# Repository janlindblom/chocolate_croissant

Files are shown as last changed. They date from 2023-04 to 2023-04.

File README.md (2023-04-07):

# The Chocolate Croissant

Yeah the name is stupid, I know.

This is a breakout board for when you want to fit a Raspberry Pi [34] B hat
onto a Raspberry Pi Pico or fit a Raspberry Pi Pico in something that expects a
full Raspberry Pi [34] B+.

The Raspberry Pi Pico W fits too of course.

## Pinout

The pinout might not be what you expect since the idea is to map function to
function rather than GPIO pin to pin.

By this I mean that the Pico I2C0 pins are mapped to the I<sup>2</sup>C pins of the
Raspberry Pi B+, SPI0 on the Pico is mapped to the SPI of the Raspberry Pi B+
and so on.

| Pin | Func | Func | Pin |
| :-- | :--- | :--- | --: |
| 1 | +3.3V | +5V | 2 |
| 3 | SDA0/GPIO4 | +5V | 4 |
| 5 | SCL0/GPIO5 | GND | 6 |
| 7 | GPIO6 | TX/GPIO0 | 8 |
| 9 | GND | RX/GPIO1 | 10  |
| 11  | GPIO11 | SPI1_CS/GPIO13 | 12  |
| 13  | *TODO* | GND | 14  |
| 15  | GPIO20 | GPIO21 | 16  |
| 17  | +3.3V | GPIO22 | 18  |
| 19  | SPI0_MOSI/GPIO19 | GND | 20  |
| 21  | SPI0_MISO/GPIO16 | GPIO23 | 22  |
| 23  | SPI0_SCK/GPIO18  | SPI0_CS/GPIO17 | 24  |
| 25  | GND | GPIO9 | 26  |
| 27  | SDA1/GPIO26 | SCL1/GPIO27 | 28  |
| 29  | GPIO7 | GND | 30  |
| 31  | GPIO8 | PWM1A/GPIO2 | 32  |
| 33  | PWM1B/GPIO3 | GND | 34  |
| 35  | SPI1_MISO/GPIO12 | GPIO10 | 36  |
| 37  | *TODO* | SPI1_MOSI/GPIO12 | 38  |
| 39  | GND | SPI1_SCK/GPIO14  | 40  |

There are two pins that are not currently connected to anything, these are
Raspberry Pi B+ pins `GPIO26` and `GPIO27`. They should obviously be connected,
the question is to what they should be connected. Maybe I need to rethink the
mapping of other stuff since I don't really have any more pins to connect from
the Pico.

### Special Breakouts

There are a couple of special breakouts avaiable:

- I<sup>2</sup>C - Four pin connector for general I<sup>2</sup>C devices
- SPI - Two SPI pin connectors:
  - Six pin SPI to fit SPI devices with six pins
  - Eight pin SPI to fit SPI devices with eight pins
- Qwiic/STEMMA QT - Two placements for Qwiic/STEMMA QT connectors:
  - I<sup>2</sup>C connected to I2C0 on the Pico
  - I<sup>2</sup>C connected to the debug pins

## Images

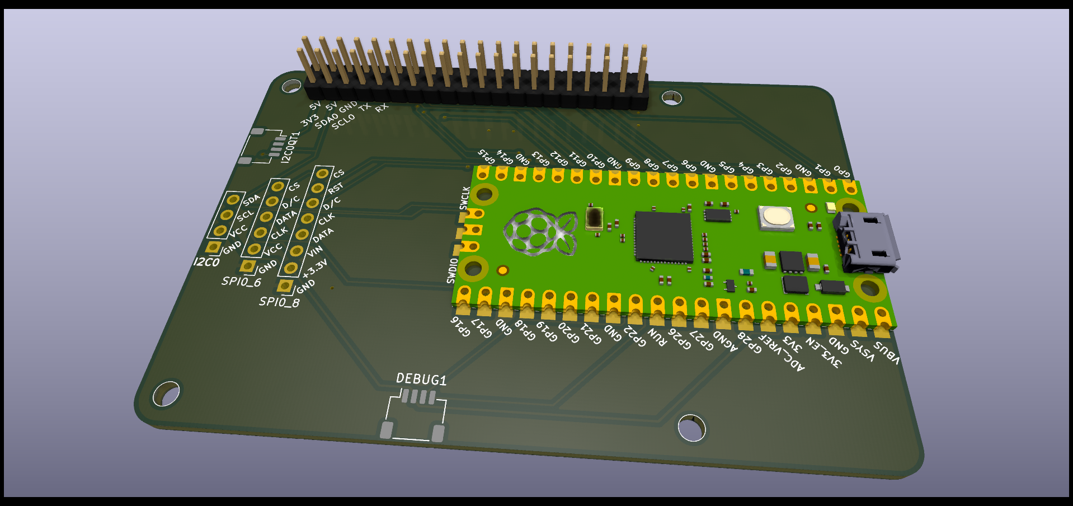
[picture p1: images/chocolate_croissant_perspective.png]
Chocolate Croissant Perspective View


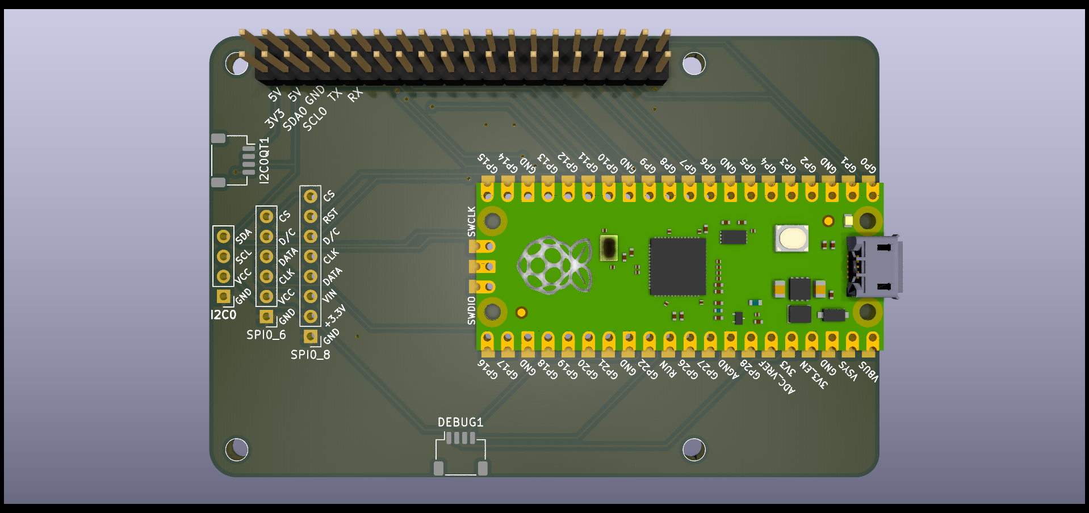
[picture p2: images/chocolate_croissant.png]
Chocolate Croissant Front View


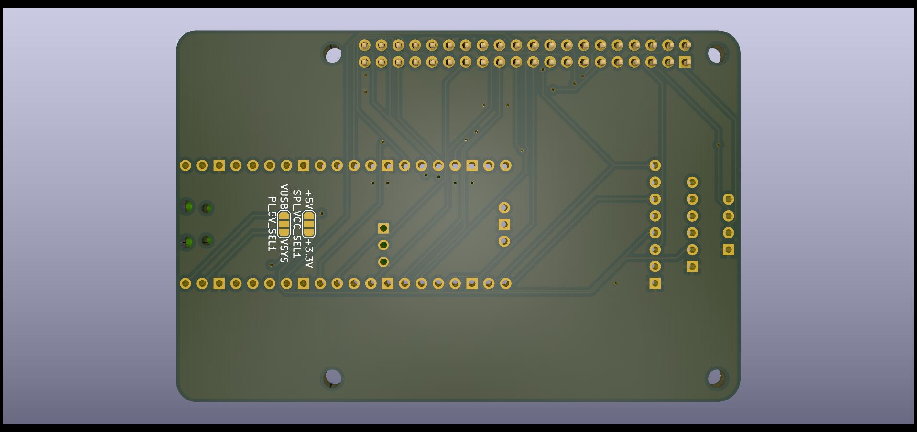
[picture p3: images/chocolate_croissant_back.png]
Chocolate Croissant Back View


## TODO

- [ ] Connect Raspberry Pi B+ pins `GPIO26` and `GPIO27` (**NOTE:** To what??)
- [ ] Add a reset button somewhere and set it up to Pico pin `RUN` maybe(?)
- [x] Add some more "special" breakouts to enable attaching debug headers,
  displays, I<sup>2</sup>C/SPI stuff...
- [x] Describe any and all "special" breakouts, like the I<sup>2</sup>C mounting
  holes

## Future/Other Work

The `over_the_top` folder holds stuff related to the "over the top" version
which is basically a full blown RP2040 on a Raspberry Pi B+ board, it's based on
the KB2040 and the Raspberry Pi Pico datasheet and has a ton of tiny SMD
components that needs to be soldered to the board.

The idea is to use JLCPCB soldering services to have them all connected but that
requires some more research into which components they offer and such.

It's far from done and isn't really useful yet. Might finish it, might not. The
biggest hurdle is to get a wireless chip and antenna onto it, but I don't know
which chip that would be just yet. Could probably use the same as the Pico W,
but I think I would need to use a different antenna.

Anyway, there are some question marks regarding licenses for the chip and
antenna used on the Pico W that seems to indicate they are not quite free to use?

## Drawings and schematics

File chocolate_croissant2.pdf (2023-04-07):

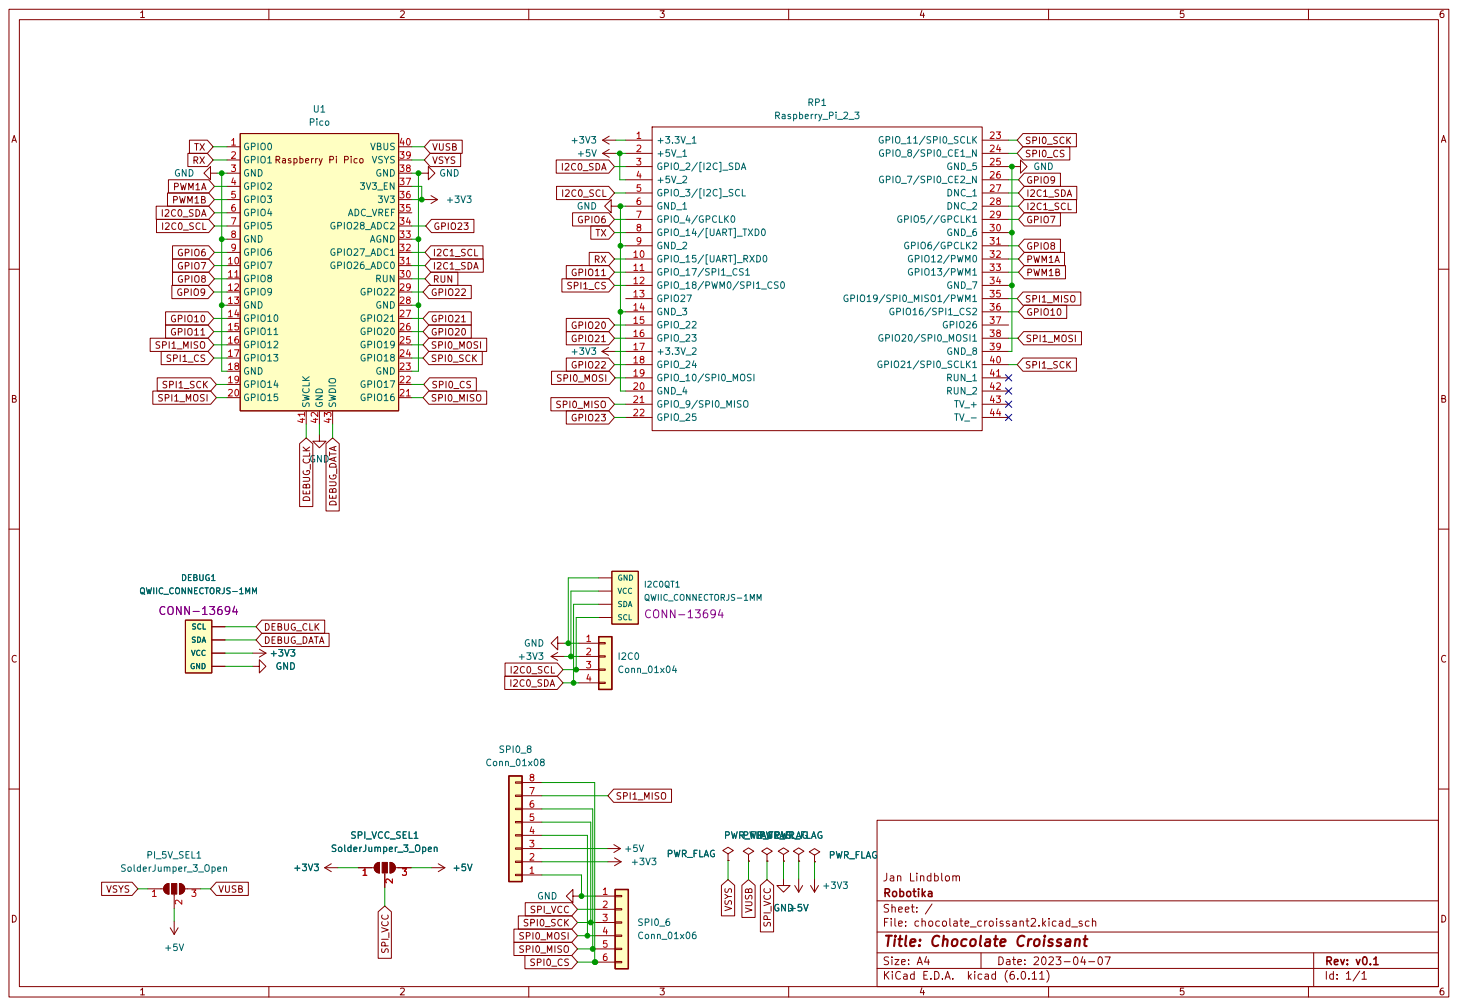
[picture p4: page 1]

Id: 1/1 Title: Chocolate Croissant File: chocolate_croissant2.kicad_sch Sheet: / Robotika

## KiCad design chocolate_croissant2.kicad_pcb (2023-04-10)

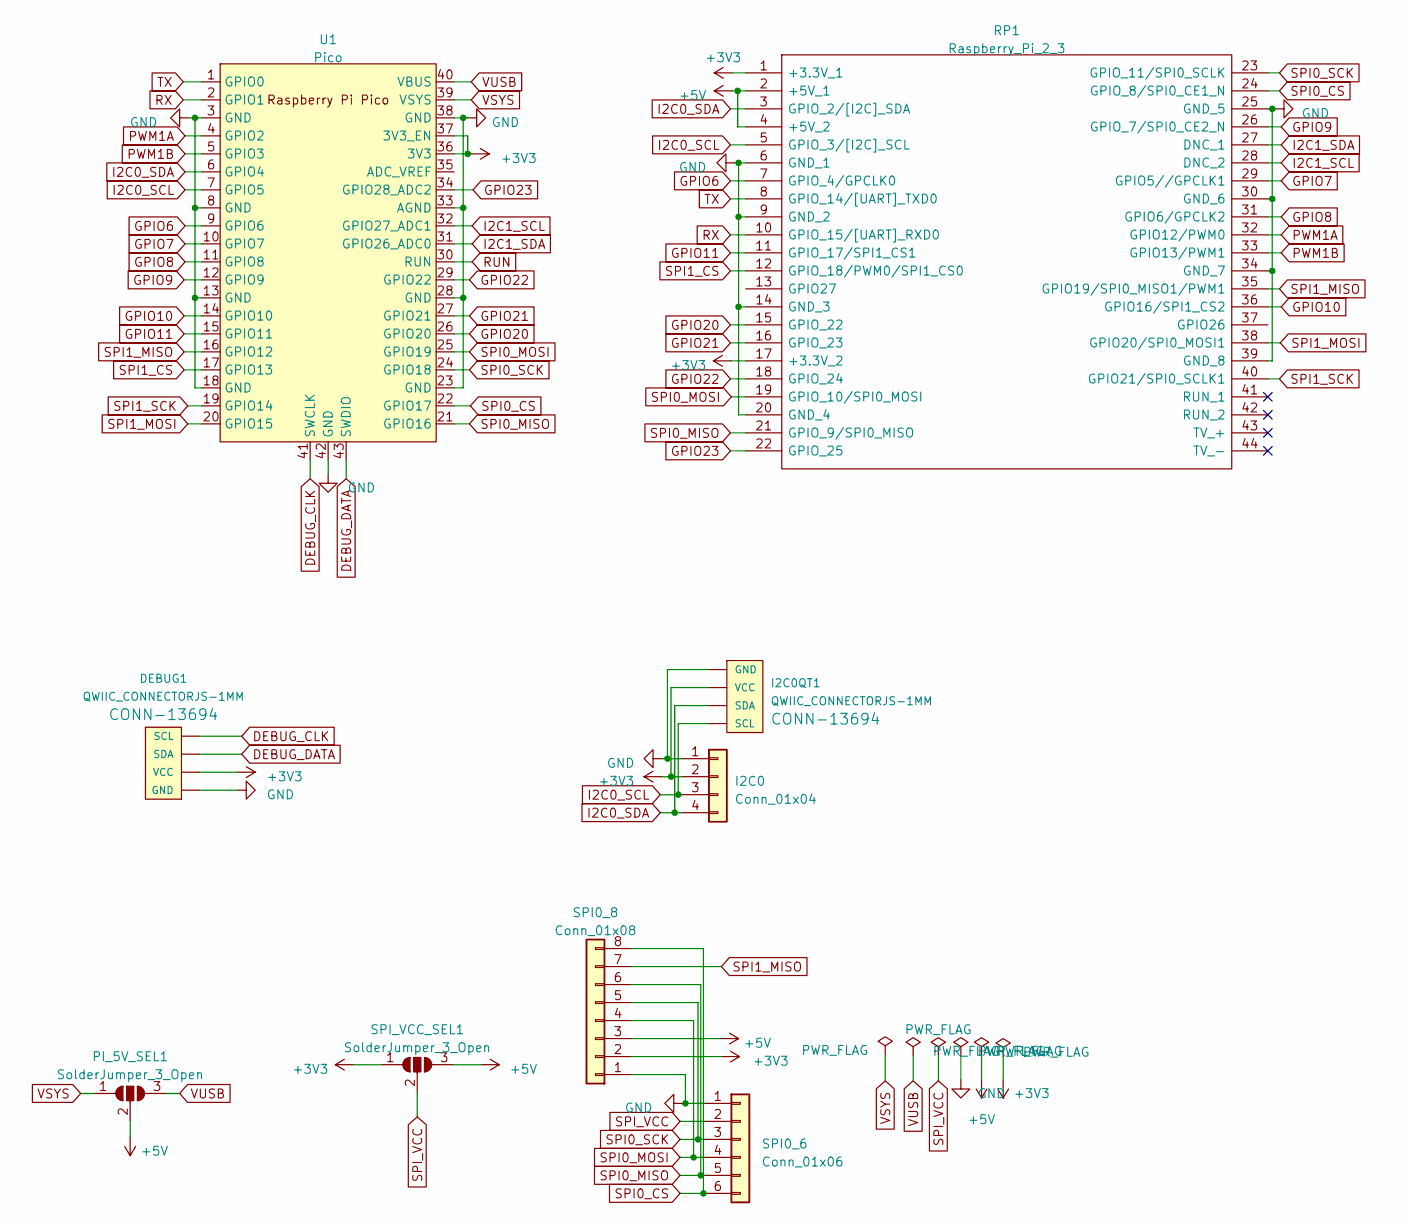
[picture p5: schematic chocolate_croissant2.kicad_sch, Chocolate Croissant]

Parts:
DEBUG1: QWIIC_CONNECTORJS-1MM; JST_SH_SM04B-SRSS-TB_1x04-1MP_P1.00mm_Horizontal
I2C0: Conn_01x04; PinHeader_1x04_P2.54mm_Vertical
I2C0QT1: QWIIC_CONNECTORJS-1MM; JST_SH_SM04B-SRSS-TB_1x04-1MP_P1.00mm_Horizontal
PI_5V_SEL1: SolderJumper_3_Open; SolderJumper-3_P1.3mm_Open_RoundedPad1.0x1.5mm_NumberLabels
RP1: Raspberry_Pi_2_3; raspberrypi_2_3; Manufacturer_Part_Number Raspberry Pi 2 or 3
SPI0_6: Conn_01x06; PinHeader_1x06_P2.54mm_Vertical
SPI0_8: Conn_01x08; PinHeader_1x08_P2.54mm_Vertical
SPI_VCC_SEL1: SolderJumper_3_Open; SolderJumper-3_P1.3mm_Open_RoundedPad1.0x1.5mm_NumberLabels
U1: Pico; RPi_Pico_SMD_TH

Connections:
+3V3: DEBUG1.2 (VCC), I2C0.2, I2C0QT1.2 (VCC), RP1.1 (+3.3V_1), RP1.17 (+3.3V_2), SPI0_8.2, SPI_VCC_SEL1.1 (A), U1.36 (3V3), U1.37 (3V3_EN)
+5V: PI_5V_SEL1.2 (C), RP1.2 (+5V_1), RP1.4 (+5V_2), SPI0_8.3, SPI_VCC_SEL1.3 (B)
DEBUG_CLK: DEBUG1.4 (SCL), U1.41 (SWCLK)
DEBUG_DATA: DEBUG1.3 (SDA), U1.43 (SWDIO)
GND: DEBUG1.1 (GND), I2C0.1, I2C0QT1.1 (GND), RP1.6 (GND_1), RP1.9 (GND_2), RP1.14 (GND_3), RP1.20 (GND_4), RP1.25 (GND_5), RP1.30 (GND_6), RP1.34 (GND_7), RP1.39 (GND_8), SPI0_6.1, SPI0_8.1, U1.3 (GND), U1.8 (GND), U1.13 (GND), U1.18 (GND), U1.23 (GND), U1.28 (GND), U1.33 (AGND), U1.38 (GND), U1.42 (GND)
GPIO6: RP1.7 (GPIO_4/GPCLK0), U1.9 (GPIO6)
GPIO7: RP1.29 (GPIO5//GPCLK1), U1.10 (GPIO7)
GPIO8: RP1.31 (GPIO6/GPCLK2), U1.11 (GPIO8)
GPIO9: RP1.26 (GPIO_7/SPI0_CE2_N), U1.12 (GPIO9)
GPIO10: RP1.36 (GPIO16/SPI1_CS2), U1.14 (GPIO10)
GPIO11: RP1.11 (GPIO_17/SPI1_CS1), U1.15 (GPIO11)
GPIO20: RP1.15 (GPIO_22), U1.26 (GPIO20)
GPIO21: RP1.16 (GPIO_23), U1.27 (GPIO21)
GPIO22: RP1.18 (GPIO_24), U1.29 (GPIO22)
GPIO23: RP1.22 (GPIO_25), U1.34 (GPIO28_ADC2)
I2C0_SCL: I2C0.3, I2C0QT1.4 (SCL), RP1.5 (GPIO_3/[I2C]_SCL), U1.7 (GPIO5)
I2C0_SDA: I2C0.4, I2C0QT1.3 (SDA), RP1.3 (GPIO_2/[I2C]_SDA), U1.6 (GPIO4)
I2C1_SCL: RP1.28 (DNC_2), U1.32 (GPIO27_ADC1)
I2C1_SDA: RP1.27 (DNC_1), U1.31 (GPIO26_ADC0)
PWM1A: RP1.32 (GPIO12/PWM0), U1.4 (GPIO2)
PWM1B: RP1.33 (GPIO13/PWM1), U1.5 (GPIO3)
RUN: U1.30 (RUN)
RX: RP1.10 (GPIO_15/[UART]_RXD0), U1.2 (GPIO1)
SPI0_CS: RP1.24 (GPIO_8/SPI0_CE1_N), SPI0_6.6, SPI0_8.8, U1.22 (GPIO17)
SPI0_MISO: RP1.21 (GPIO_9/SPI0_MISO), SPI0_6.5, SPI0_8.6, U1.21 (GPIO16)
SPI0_MOSI: RP1.19 (GPIO_10/SPI0_MOSI), SPI0_6.4, SPI0_8.4, U1.25 (GPIO19)
SPI0_SCK: RP1.23 (GPIO_11/SPI0_SCLK), SPI0_6.3, SPI0_8.5, U1.24 (GPIO18)
SPI1_CS: RP1.12 (GPIO_18/PWM0/SPI1_CS0), U1.17 (GPIO13)
SPI1_MISO: RP1.35 (GPIO19/SPI0_MISO1/PWM1), SPI0_8.7, U1.16 (GPIO12)
SPI1_MOSI: RP1.38 (GPIO20/SPI0_MOSI1), U1.20 (GPIO15)
SPI1_SCK: RP1.40 (GPIO21/SPI0_SCLK1), U1.19 (GPIO14)
SPI_VCC: SPI0_6.2, SPI_VCC_SEL1.2 (C)
TX: RP1.8 (GPIO_14/[UART]_TXD0), U1.1 (GPIO0)
VSYS: PI_5V_SEL1.1 (A), U1.39 (VSYS)
VUSB: PI_5V_SEL1.3 (B), U1.40 (VBUS)

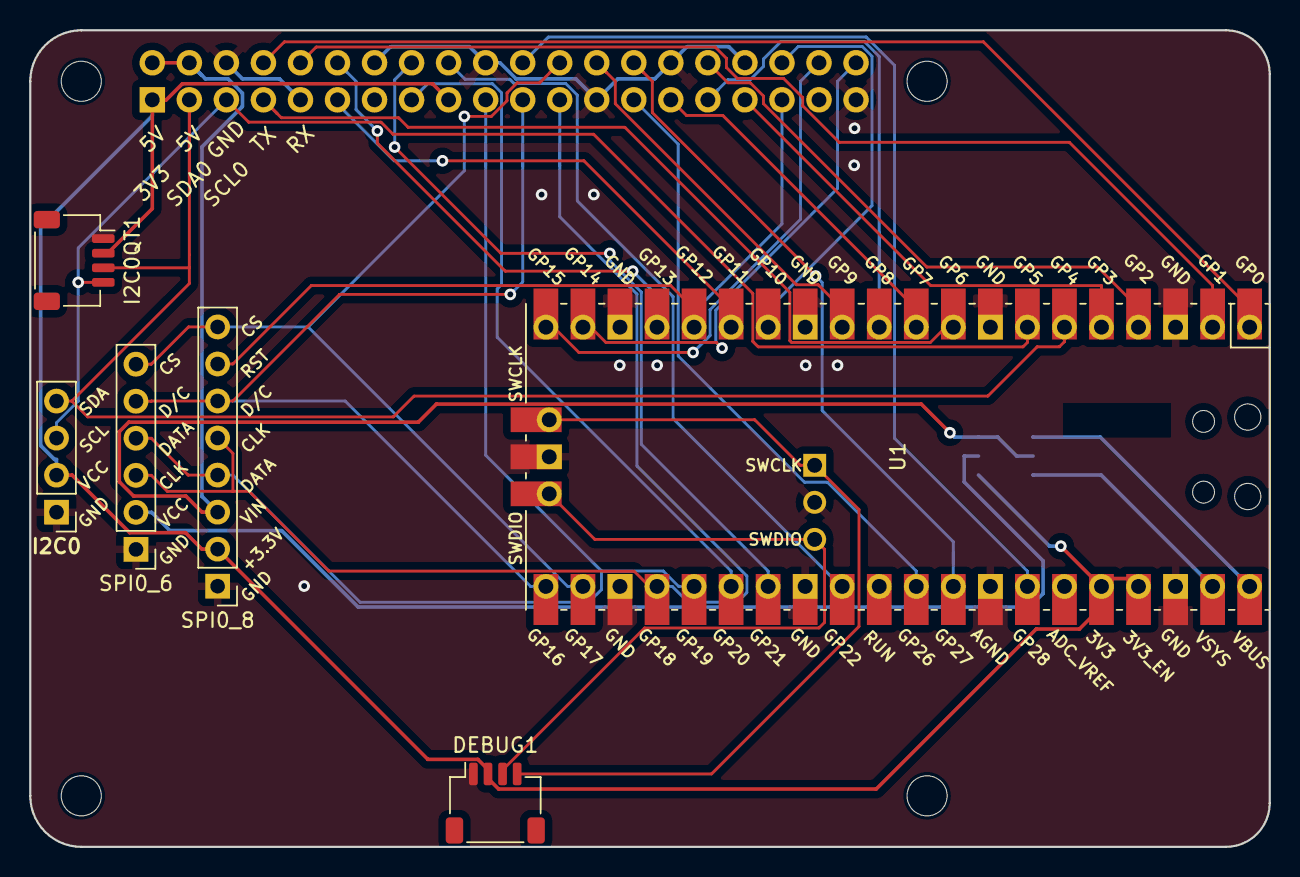
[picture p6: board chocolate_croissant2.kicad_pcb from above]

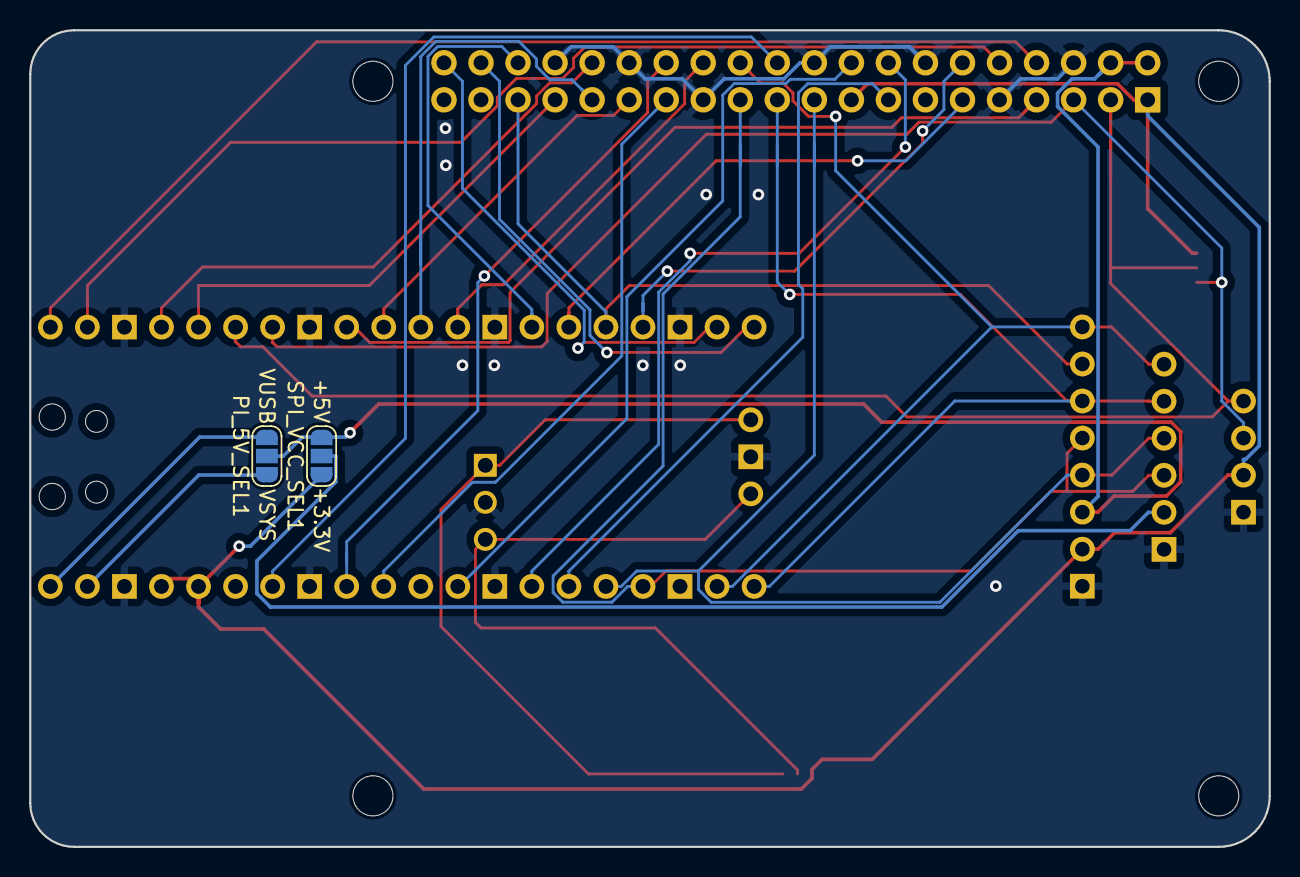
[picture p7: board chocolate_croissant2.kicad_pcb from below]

Board: 2 copper layers, 85.0 x 56.0 mm, 9 parts (2 on the bottom side), 34 nets.

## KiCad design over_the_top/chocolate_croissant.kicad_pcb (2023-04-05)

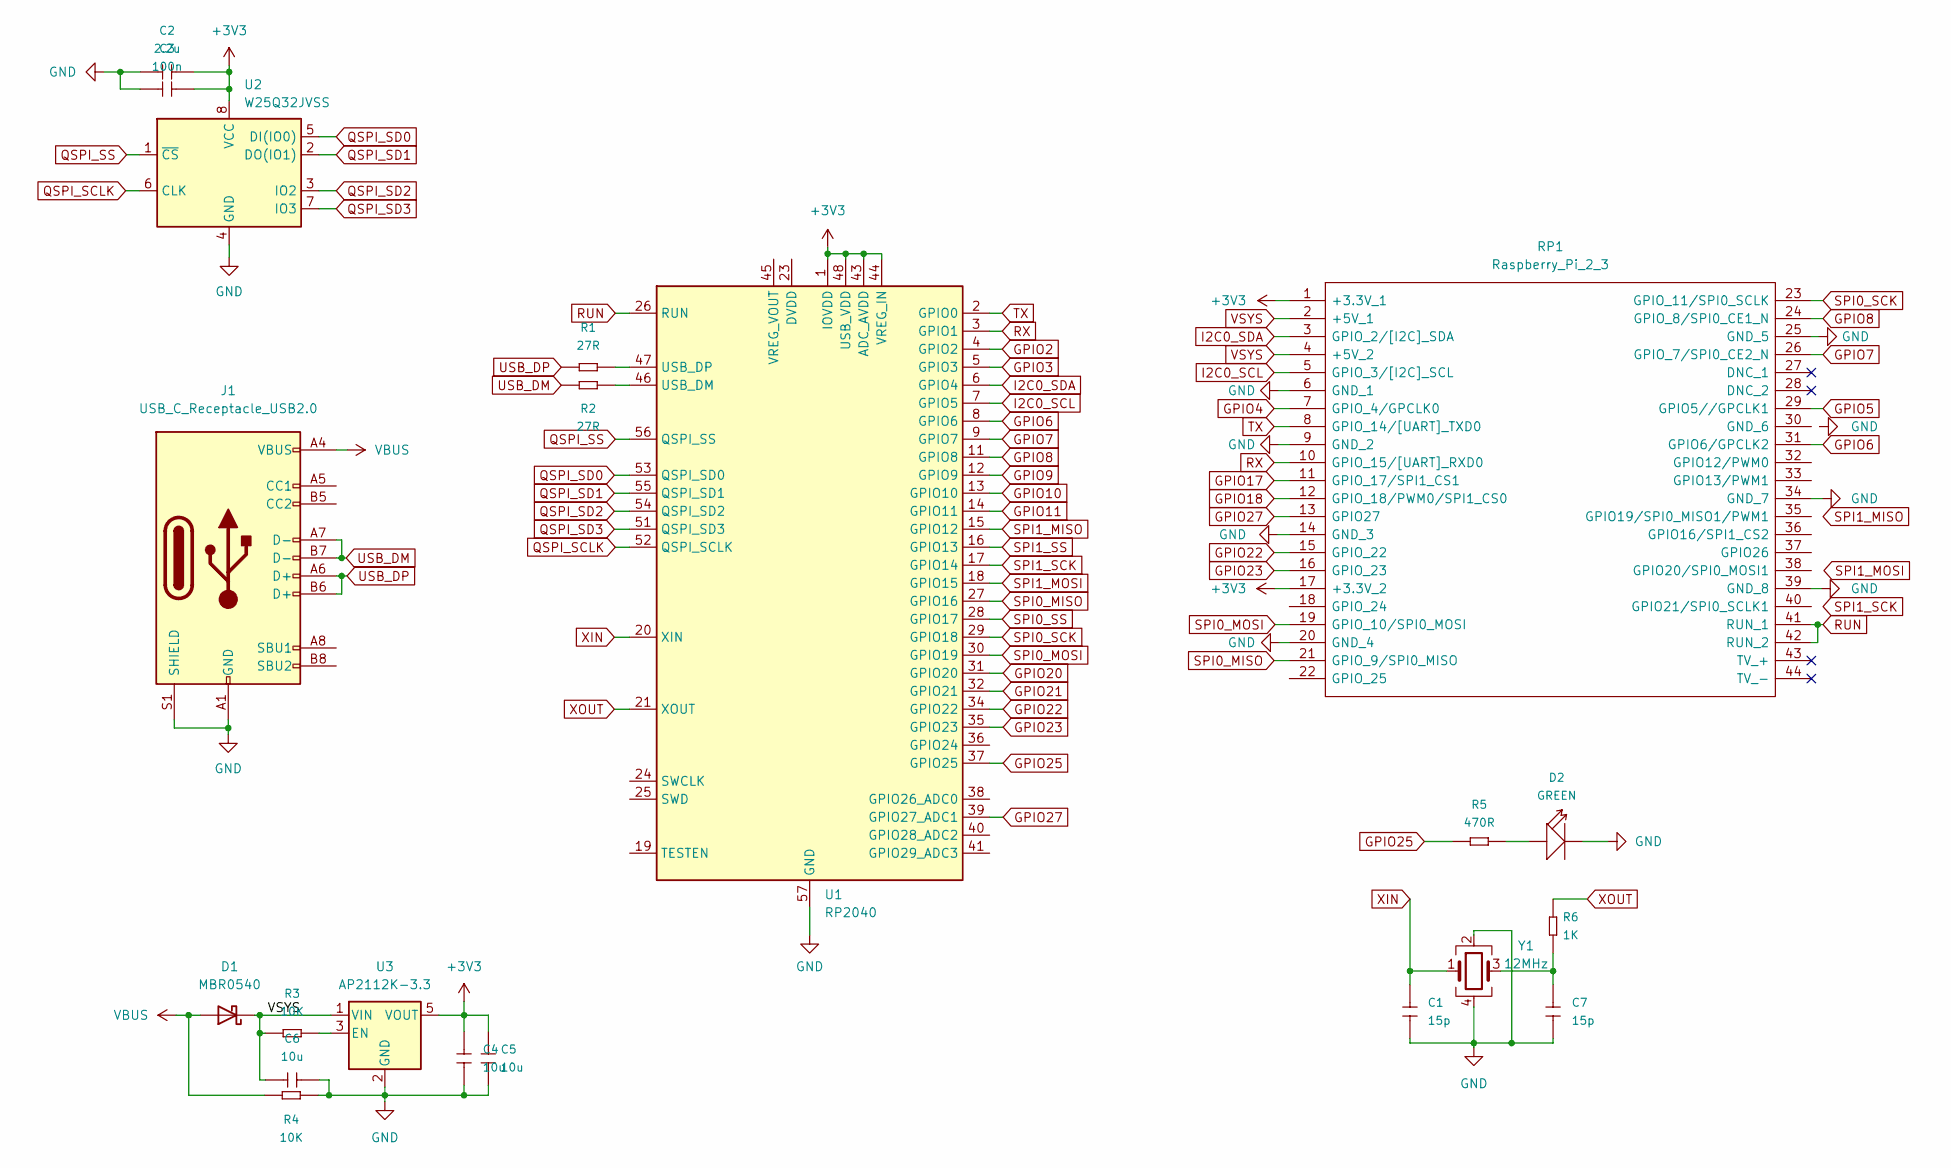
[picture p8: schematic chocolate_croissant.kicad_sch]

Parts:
C1, C7: 15p; C_1206_3216Metric_Pad1.33x1.80mm_HandSolder; MPN GRM31CR60J107ME39L
C2: 2.2u; C_0805_2012Metric_Pad1.18x1.45mm_HandSolder; MPN GRM31CR60J107ME39L
C3: 100n; C_0805_2012Metric_Pad1.18x1.45mm_HandSolder; MPN GRM31CR60J107ME39L
C4, C5, C6: 10u; C_1206_3216Metric_Pad1.33x1.80mm_HandSolder; MPN GRM31CR60J107ME39L
D1: MBR0540; D_SOD-123
D2: GREEN; LED_0805_2012Metric_Pad1.15x1.40mm_HandSolder; MPN 17-215SYGC_S530-E2_TR8
J1: USB_C_Receptacle_USB2.0; USB_C_Receptacle_Palconn_UTC16-G
R1, R2: 27R; R_0805_2012Metric_Pad1.20x1.40mm_HandSolder; MPN RC0603FR-0720KL
R3, R4: 10K; R_0603_1608Metric_Pad0.98x0.95mm_HandSolder; MPN RC0603FR-0720KL
R5: 470R; R_0603_1608Metric_Pad0.98x0.95mm_HandSolder; MPN RC0603FR-0720KL
R6: 1K; R_0603_1608Metric_Pad0.98x0.95mm_HandSolder; MPN RC0603FR-0720KL
RP1: Raspberry_Pi_2_3; raspberrypi_2_3; Manufacturer_Part_Number Raspberry Pi 2 or 3
U1: RP2040; QFN-56-1EP_7x7mm_P0.4mm_EP3.2x3.2mm
U2: W25Q32JVSS; SOIC-8_5.23x5.23mm_P1.27mm
U3: AP2112K-3.3; SOT-23-5
Y1: 12MHz; Crystal_SMD_0603-4Pin_6.0x3.5mm_HandSoldering

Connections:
+3V3: C2.2, C3.2, C4.1, C5.1, RP1.1 (+3.3V_1), RP1.17 (+3.3V_2), U1.1 (IOVDD), U1.10 (IOVDD), U1.22 (IOVDD), U1.33 (IOVDD), U1.42 (IOVDD), U1.43 (ADC_AVDD), U1.44 (VREG_IN), U1.48 (USB_VDD), U1.49 (IOVDD), U2.8 (VCC), U3.5 (VOUT)
GND: C1.1, C2.1, C3.1, C4.2, C5.2, C6.2, C7.1, D2.2 (-), J1.A1 (GND), J1.A12 (GND), J1.B1 (GND), J1.B12 (GND), J1.S1 (SHIELD), R4.2, RP1.6 (GND_1), RP1.9 (GND_2), RP1.14 (GND_3), RP1.20 (GND_4), RP1.25 (GND_5), RP1.34 (GND_7), RP1.39 (GND_8), U1.57 (GND), U2.4 (GND), U3.2 (GND), Y1.2, Y1.4
GPIO2: U1.4 (GPIO2)
GPIO3: U1.5 (GPIO3)
GPIO4: RP1.7 (GPIO_4/GPCLK0)
GPIO5: RP1.29 (GPIO5//GPCLK1)
GPIO6: RP1.31 (GPIO6/GPCLK2), U1.8 (GPIO6)
GPIO7: RP1.26 (GPIO_7/SPI0_CE2_N), U1.9 (GPIO7)
GPIO8: RP1.24 (GPIO_8/SPI0_CE1_N), U1.11 (GPIO8)
GPIO9: U1.12 (GPIO9)
GPIO10: U1.13 (GPIO10)
GPIO11: U1.14 (GPIO11)
GPIO17: RP1.11 (GPIO_17/SPI1_CS1)
GPIO18: RP1.12 (GPIO_18/PWM0/SPI1_CS0)
GPIO20: U1.31 (GPIO20)
GPIO21: U1.32 (GPIO21)
GPIO22: RP1.15 (GPIO_22), U1.34 (GPIO22)
GPIO23: RP1.16 (GPIO_23), U1.35 (GPIO23)
GPIO25: R5.1, U1.37 (GPIO25)
GPIO27: RP1.13 (GPIO27), U1.39 (GPIO27_ADC1)
I2C0_SCL: RP1.5 (GPIO_3/[I2C]_SCL), U1.7 (GPIO5)
I2C0_SDA: RP1.3 (GPIO_2/[I2C]_SDA), U1.6 (GPIO4)
unnamed: C7.2, R6.1, Y1.3
unnamed: D2.1 (+), R5.2
unnamed: R3.2, U3.3 (EN)
unnamed: U1.23 (DVDD), U1.50 (DVDD)
unnamed: R2.2, U1.46 (USB_DM)
unnamed: R1.2, U1.47 (USB_DP)
QSPI_SCLK: U1.52 (QSPI_SCLK), U2.6 (CLK)
QSPI_SD0: U1.53 (QSPI_SD0), U2.5 (DI(IO0))
QSPI_SD1: U1.55 (QSPI_SD1), U2.2 (DO(IO1))
QSPI_SD2: U1.54 (QSPI_SD2), U2.3 (IO2)
QSPI_SD3: U1.51 (QSPI_SD3), U2.7 (IO3)
QSPI_SS: U1.56 (QSPI_SS), U2.1 (~CS)
RUN: RP1.41 (RUN_1), RP1.42 (RUN_2), U1.26 (RUN)
RX: RP1.10 (GPIO_15/[UART]_RXD0), U1.3 (GPIO1)
SPI0_MISO: RP1.21 (GPIO_9/SPI0_MISO), U1.27 (GPIO16)
SPI0_MOSI: RP1.19 (GPIO_10/SPI0_MOSI), U1.30 (GPIO19)
SPI0_SCK: RP1.23 (GPIO_11/SPI0_SCLK), U1.29 (GPIO18)
SPI0_SS: U1.28 (GPIO17)
SPI1_MISO: U1.15 (GPIO12)
SPI1_MOSI: U1.18 (GPIO15)
SPI1_SCK: U1.17 (GPIO14)
SPI1_SS: U1.16 (GPIO13)
TX: RP1.8 (GPIO_14/[UART]_TXD0), U1.2 (GPIO0)
USB_DM: J1.A7 (D-), J1.B7 (D-), R2.1
USB_DP: J1.A6 (D+), J1.B6 (D+), R1.1
VBUS: D1.2 (A), J1.A4 (VBUS), J1.A9 (VBUS), J1.B4 (VBUS), J1.B9 (VBUS), R4.1
VSYS: C6.1, D1.1 (K), R3.1, RP1.2 (+5V_1), RP1.4 (+5V_2), U3.1 (VIN)
XIN: C1.2, U1.20 (XIN), Y1.1
XOUT: R6.2, U1.21 (XOUT)

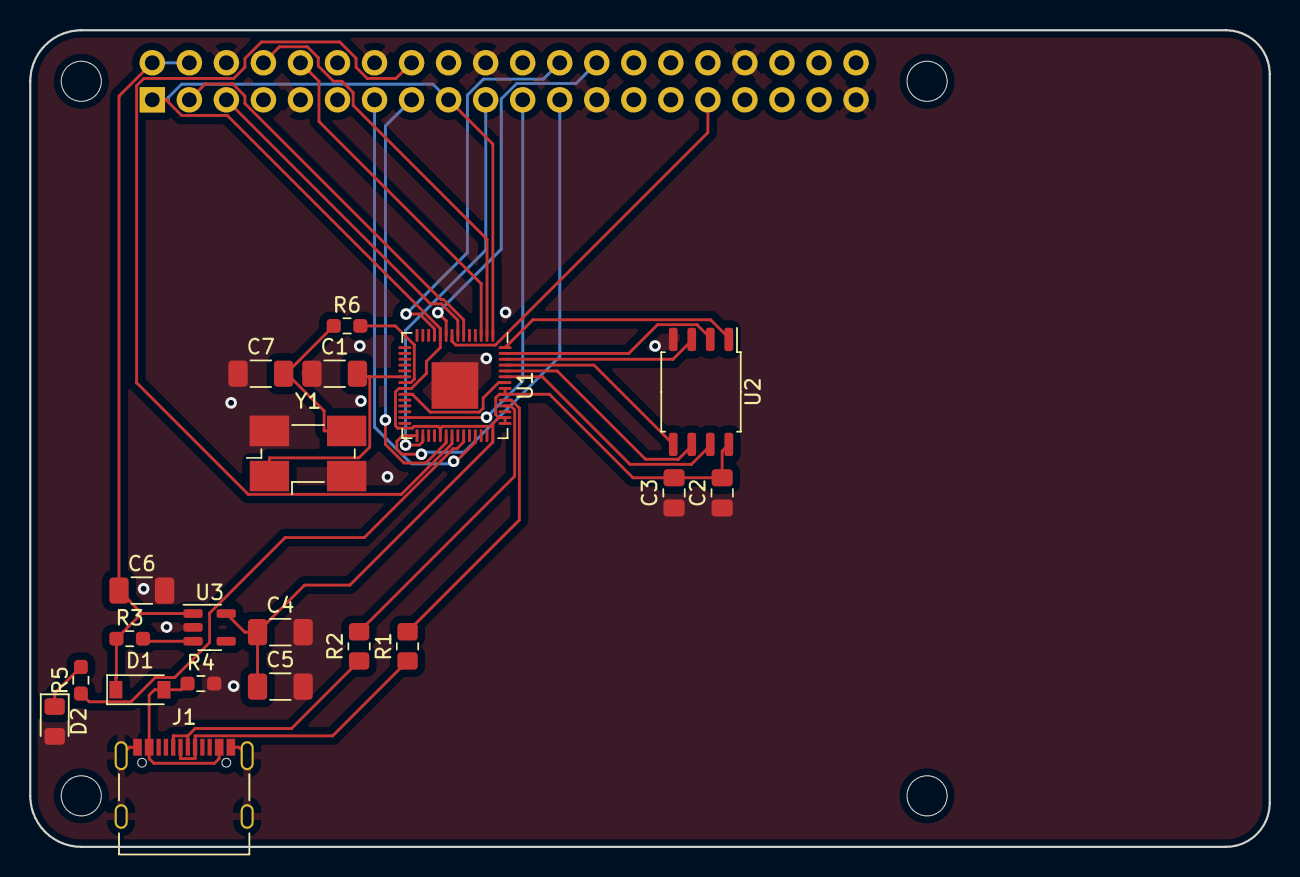
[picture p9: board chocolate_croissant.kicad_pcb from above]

Board: 2 copper layers, 85.0 x 56.0 mm, 21 parts (0 on the bottom side), 34 nets.

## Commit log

2023-04-05 Initial commit, work in progress.
    [chocolate_croissant.kicad_pcb, chocolate_croissant.kicad_sch, chocolate_croissant2.kicad_pcb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]
2023-04-05 Image of the back of the PCB added to README.
    [chocolate_croissant2.kicad_pcb]
2023-04-06 SPI breakouts and new images.
    [chocolate_croissant2.kicad_pcb, chocolate_croissant2.kicad_sch]
2023-04-07 Cleaning up the files a bit.
    [chocolate_croissant.kicad_pcb, chocolate_croissant.kicad_sch]
2023-04-07 Adding some more stuff, more documentation in the README etc.
    [chocolate_croissant2.kicad_pcb, chocolate_croissant2.kicad_sch]
2023-04-10 KiCad 7 plus local footprints and symbols.
    [chocolate_croissant2.kicad_pcb, chocolate_croissant2.kicad_sch]
